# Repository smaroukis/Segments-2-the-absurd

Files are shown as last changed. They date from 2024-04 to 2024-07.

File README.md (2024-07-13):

For now, see <https://maroukis.net/sev-seg> 

> [!CAUTION] You will need to run a `git submodule init && git submodule update` to pull in changes to the TM1637 Seven Segment driver submodule code

## Building 
In the MCU directory i.e. `src/stm32` run `make flash`, see Makefile and VSCode `tasks.json` for details.

## Dependencies
- a forked version of nimaltd/tm1637 as a submodule in src/.../ThirdParty/tm1637 

Update the submodule _within the submodule directory_:
- `git fetch` && `git merge upstream/main`

# Revision History

## 2024-07-13 - Prototype (v-alpha) Hardware Finished
- __note kicad files and production gerbers are not in sync at this point__
- cleaned up git status in preparation for firmware development
- note at this point some edits were made to the kicad files that make it out of sync with the production file from commit #(TODO)
- moved prototype datasheets into a specific folder `.../2024-05-27-v-alpha`

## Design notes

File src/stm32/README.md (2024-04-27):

## Overview

- Build process is via the Makefile using the `arm-none-eabi-gcc` version as installed via the STM32 command line tools 
- Firmware upload & Debuggin is done viaOpenOCD over STLink (transport interface SWD by default?)

Commands:
- Build & Flash at same time via VSCode (`CMD+SHIFT+B`) → Makefile (i.e. `make flash`) → OpenOCD 

## Important files / changes for use

GCC path: is hardcoded and not in system environment variables, but is mainly used in 
- `tasks.json` in the `GCC_PATH` environment variable when we call `make`
- for Intelliense in `c_cpp_properties.json` (for the C/C++ Extension from Microsoft)

Other things to edit
- include paths & define's in the `c_cpp_properties.json`, currently not in use but an example can be found in `c_cpp_properties_old.json` (I think this just affects Intellisense and not compilation)

## Development

(Note currently just using direct commits to `tm1637` `main` branch of submodule)

Due to using submodule (`ThirdParty/tm1637`), development process is as follows
- commit and push and changes for the submodule _before_ commiting changes for the parent
- once submodule changes are pushed, in the project root run `git add ThirdParty/tm1637` (no need for `git fetch`) to add the submodule changes (commit hash should be changed)
- develop, stage, and push changes in the parent project as normal

Tip use
`git submodule status` to see the commit we are pointing to
and compare it to:
```
cd path/to/submodule
git log -1
```

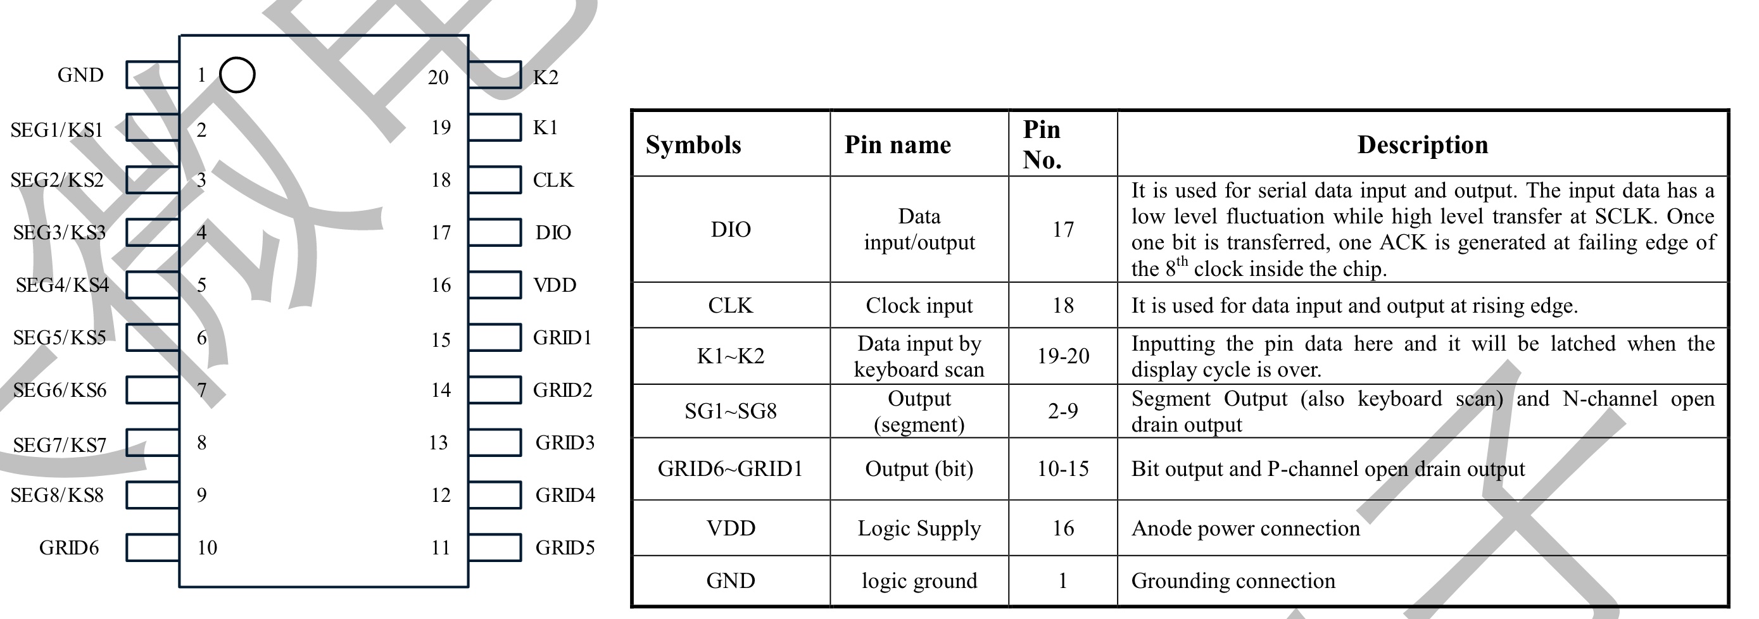
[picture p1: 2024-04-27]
assets/TM1637_pinout-w-description.jpg

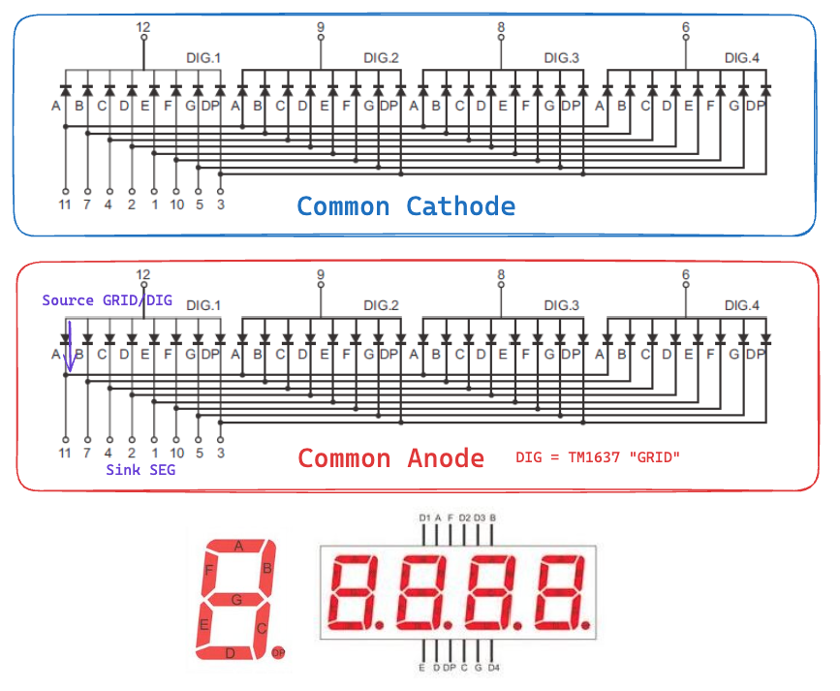
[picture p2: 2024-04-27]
assets/Generic_Seven-Segment_pinout.png

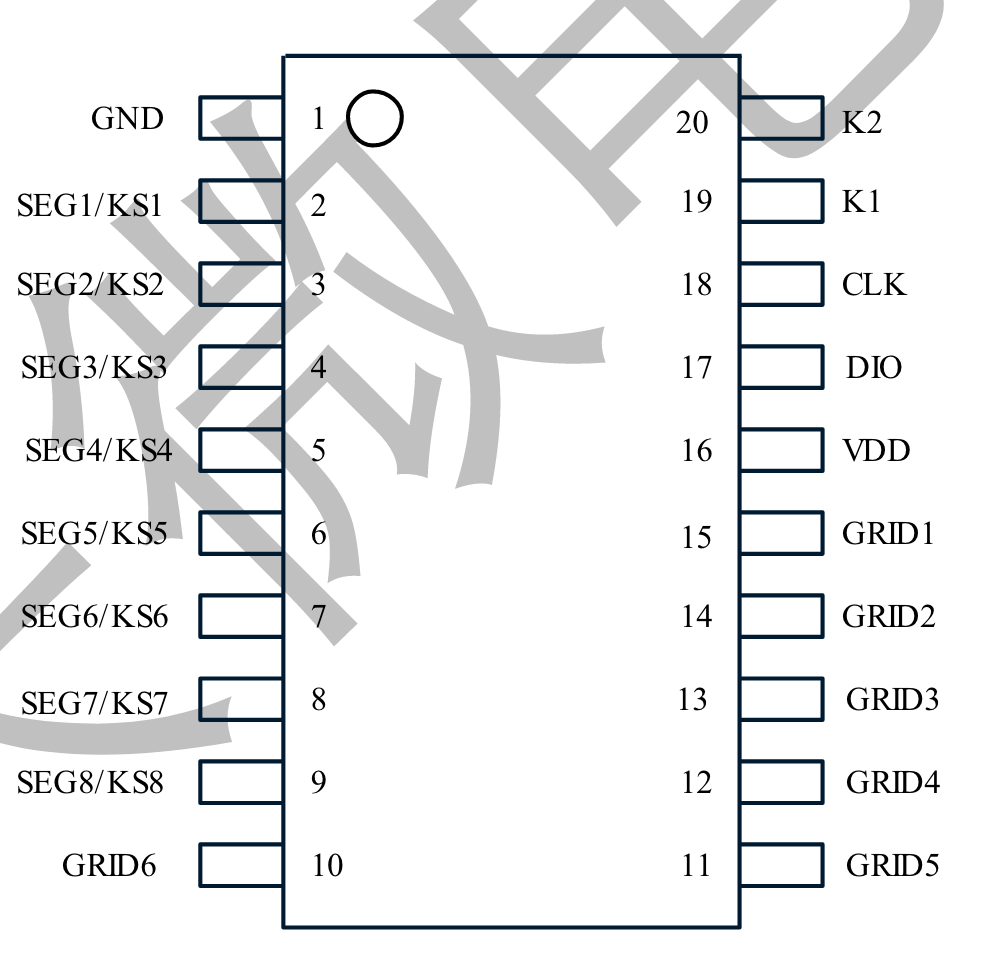
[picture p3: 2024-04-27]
assets/TM1637_pinout.png

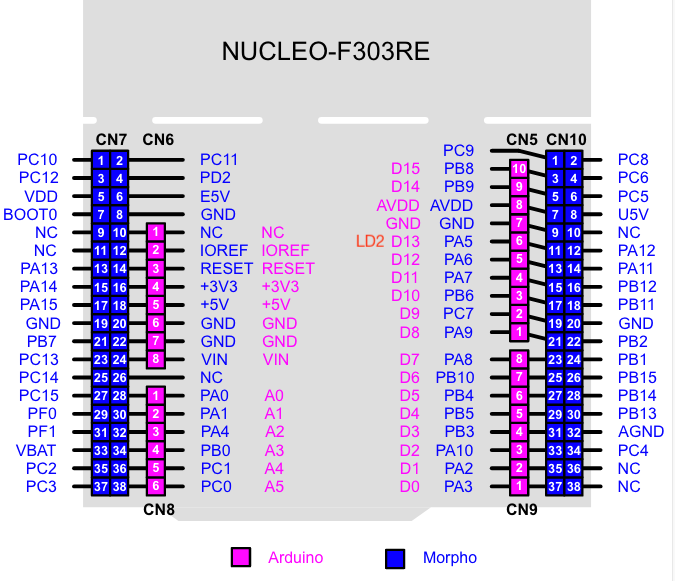
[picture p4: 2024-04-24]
assets/STM-nucleo-f303_pinout.png

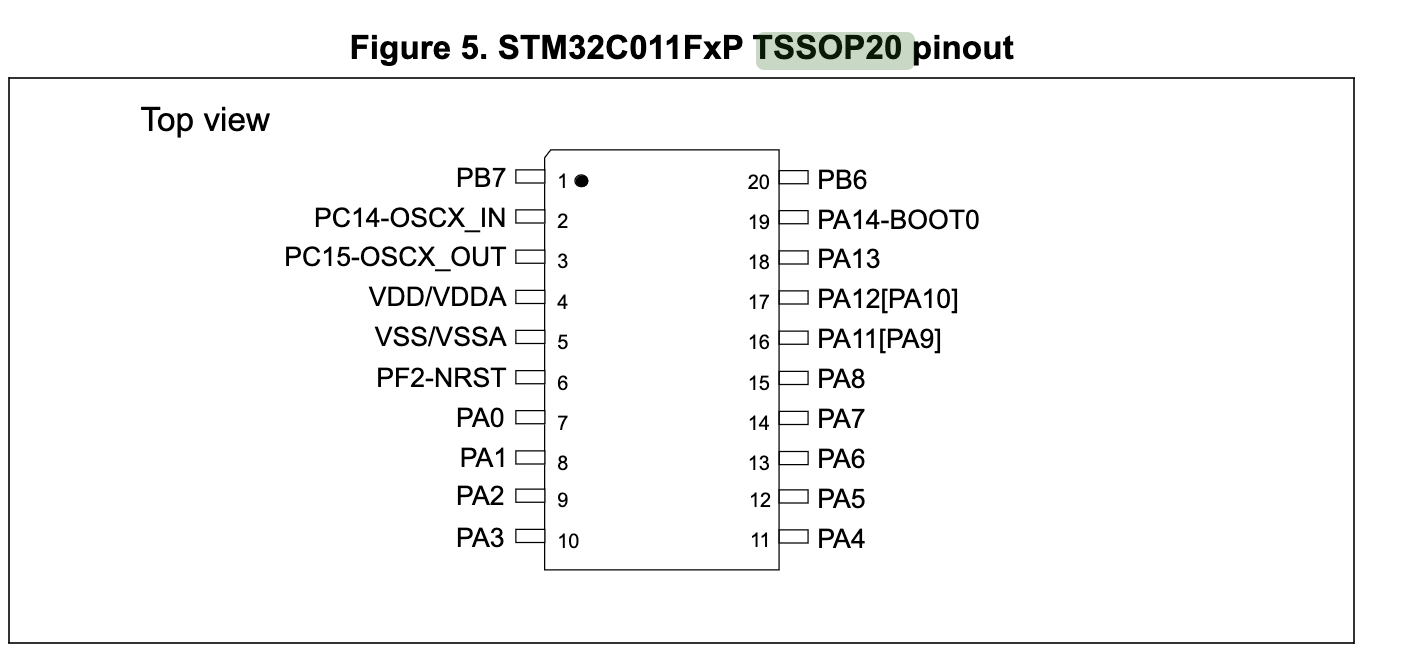
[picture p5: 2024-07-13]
kicad/00-Assets-Datasheets/2024-05-27-v-alpha/mcu-STM32C011F6P6_C5456198_PINOUT.png

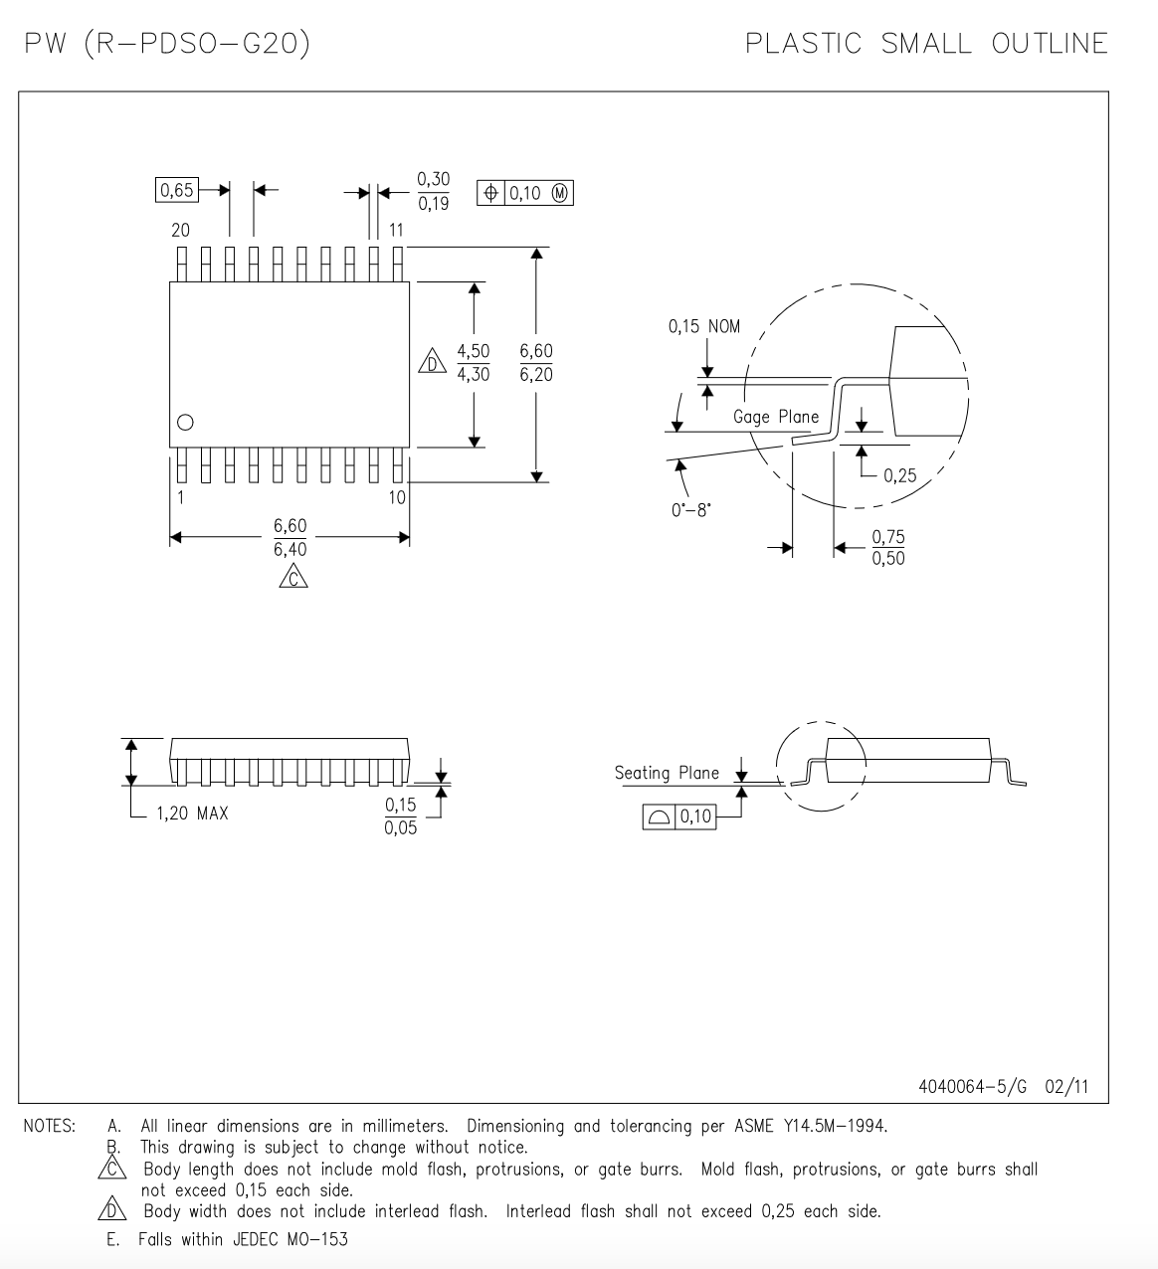
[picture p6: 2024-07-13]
kicad/00-Assets-Datasheets/2024-05-27-v-alpha/level-shifter_Texas-Instruments-TXS0108EPWR_C17206.pdf_PACKAGE.png

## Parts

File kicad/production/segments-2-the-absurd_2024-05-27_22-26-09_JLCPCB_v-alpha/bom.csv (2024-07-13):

Designator | Footprint | Quantity | Comment | LCSC Part #
C1, C13, C17, C21, C24, C26, C27, C28, C29, C31, C32, C33, C35, C39, C43, C5, C9 | 603 | 17 | 100nF | C14663
C10, C11, C14, C15, C18, C19, C22, C23, C36, C37, C40, C41, C44, C45, C6, C7 | 603 | 16 | 100pF | C14858
C12, C16, C20, C34, C38, C4, C42, C8 | 1206 | 8 | 100uF | C15008
C25, C30 | 603 | 2 | 4.7uF | C19666
J10, J11, J12, J13, J14, J15, J16, J17, J20, J9 | PinHeader_1x02_P2.54mm_Vertical | 10 | Conn_01x02_Pin | C492401
J18, J19 | PinHeader_1x03_P1.27mm_Vertical | 2 | Conn_01x03_Pin | DNP
J2 | PinHeader_1x08_P2.54mm_Vertical | 1 | Conn_01x08_Pin | DNP
J4, J6 | PinHeader_1x05_P2.54mm_Vertical | 2 | Conn_01x05_Socket | DNP
J7, J8 | PinHeader_1x02_P1.27mm_Vertical | 2 | Conn_01x02_Pin | DNP
JP1, JP2 | SolderJumper-3_P1.3mm_Bridged12_RoundedPad1.0x1.5mm | 2 | Jumper_3_Bridged12 | DNP
R1, R10, R11, R12, R13, R14, R15, R16, R17, R18, R19, R2, R20, R21, R22, R3, R4, R5, R6, R7, R8, R9 | 603 | 22 | 10K | C25804
U1 | SOP-16_3.9x9.9mm_P1.27mm | 1 | 74HC595 | C5451631
U10, U8 | TSSOP-20_4.4x6.5mm_P0.65mm | 2 | STM32C011F6Px | C5456198
U11, U12, U13, U2, U3, U4, U5, U6 | TM_TM1637(TA2007)_SOC-20_12.6x7.5_P1.27_PD0.44x2 | 8 | TM1637 | C5337160
U7, U9 | TSSOP-20_4.4x6.5mm_P0.65mm | 2 | TXS0108E | C17206

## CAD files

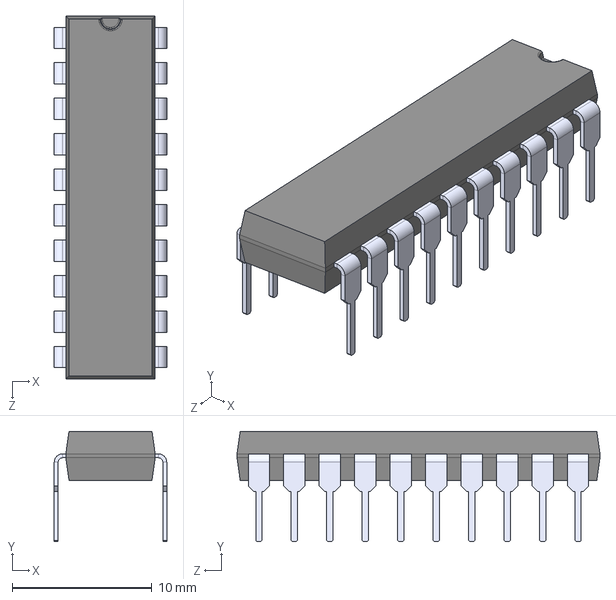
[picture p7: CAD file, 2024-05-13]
kicad/03-3D-Models/TM1637.step
8.06 x 7.91 x 26.0 mm

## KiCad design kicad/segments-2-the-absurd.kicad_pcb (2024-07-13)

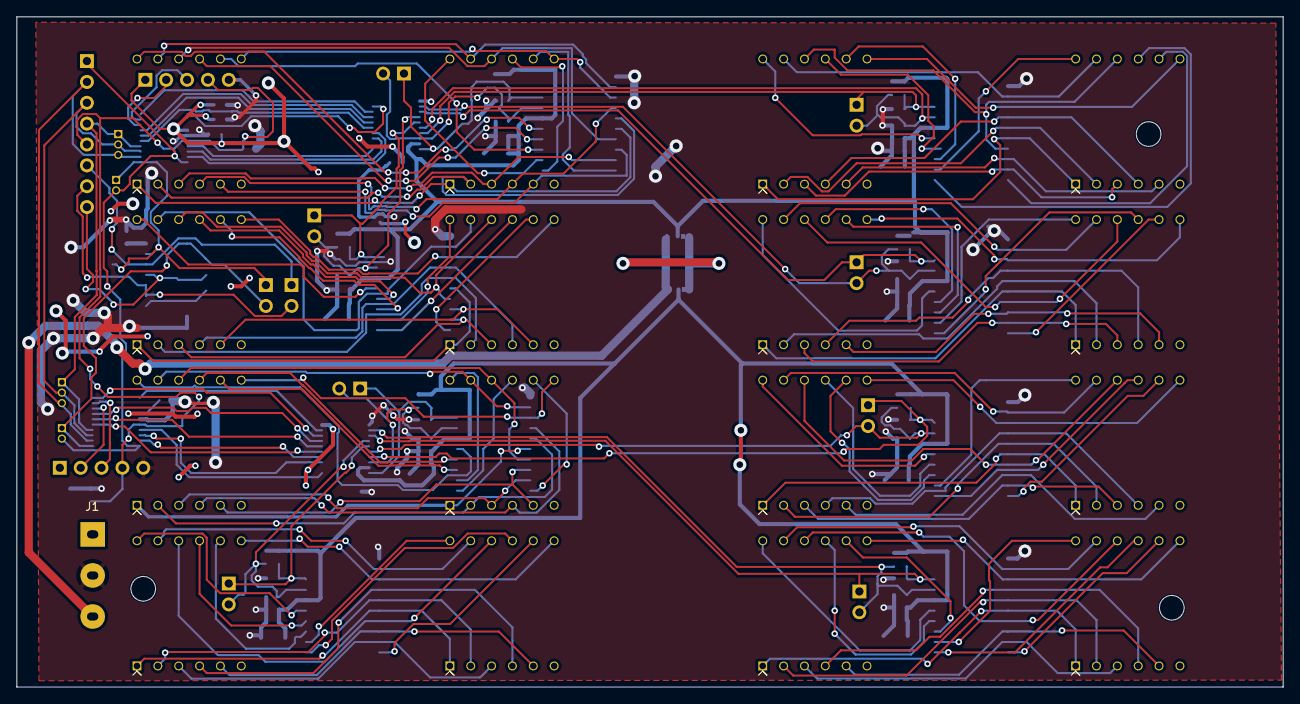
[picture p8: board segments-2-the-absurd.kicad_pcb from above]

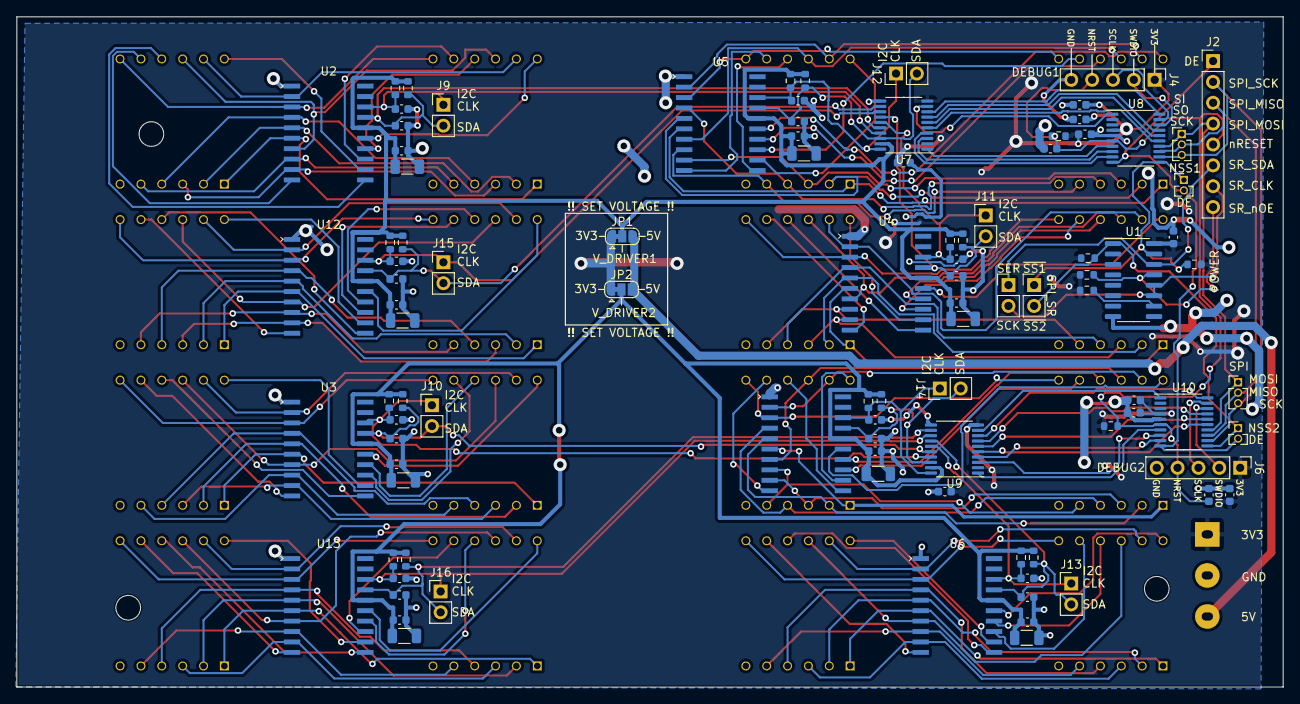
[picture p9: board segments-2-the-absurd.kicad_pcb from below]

Board: 2 copper layers, 154.2 x 81.6 mm, 114 parts (97 on the bottom side), 164 nets.

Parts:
C1, C5, C9, C13, C17, C21, C24, C26, C27, C28, C29, C31, C32, C33, C35, C39, C43: 100nF; C_0603_1608Metric
C4, C8, C12, C16, C20, C34, C38, C42: 100uF; C_1206_3216Metric
C6, C7, C10, C11, C14, C15, C18, C19, C22, C23, C36, C37, C40, C41, C44, C45: 100pF; C_0603_1608Metric
C25, C30: 4.7uF; C_0603_1608Metric
D1, D2, D3, D4, D5, D6, D7, D8, D9, D10, D11, D12, D13, D14, D15, D16: SP410561N; 7-Seg-3D_CA_ARKLED_SP410561N
J1: Conn_01x03_Pin; Power-Conn-3P-D0.65-P5-BD7.8x15
J2: Conn_01x08_Pin; PinHeader_1x08_P2.54mm_Vertical
J4, J6: Conn_01x05_Socket; PinHeader_1x05_P2.54mm_Vertical
J7, J8: Conn_01x02_Pin; PinHeader_1x02_P1.27mm_Vertical
J9, J10, J11, J12, J13, J14, J15, J16, J17, J20: Conn_01x02_Pin; PinHeader_1x02_P2.54mm_Vertical
J18, J19: Conn_01x03_Pin; PinHeader_1x03_P1.27mm_Vertical
JP1, JP2: Jumper_3_Bridged12; SolderJumper-3_P1.3mm_Bridged12_RoundedPad1.0x1.5mm
R1, R2, R3, R4, R5, R6, R7, R8, R9, R10, R11, R12, R13, R14, R15, R16, R17, R18, R19, R20, R21, R22: 10K; R_0603_1608Metric
U1: 74HC595; SOP-16_3.9x9.9mm_P1.27mm
U2, U3, U4, U5, U6, U11, U12, U13: TM1637; TM_TM1637(TA2007)_SOC-20_12.6x7.5_P1.27_PD0.44x2
U7, U9: TXS0108E; TSSOP-20_4.4x6.5mm_P0.65mm
U8, U10: STM32C011F6Px; TSSOP-20_4.4x6.5mm_P0.65mm

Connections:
+3V3: C1.2, C24.1, C25.1, C26.1, C28.2, C29.1, C30.1, C31.1, C33.2, J1.1, J4.1, J6.1, JP1.1 (A), JP2.1 (A), R1.1, R2.1, R3.1, R4.1, R15.1, R16.1, U1.16 (VCC), U7.2 (VCCA), U7.10 (OE), U8.4 (VDD), U9.2 (VCCA), U9.10 (OE), U10.4 (VDD)
+5V: J1.3, JP1.3 (B), JP2.3 (B)
/DISP_EN: J2.1, J7.2, J8.2, U8.10 (PA3), U10.10 (PA3)
/S2A_Serf1/A_CLK: C19.1, J12.1, R12.2, U5.18 (CLK), U7.20 (B1)
/S2A_Serf1/A_CLK': U7.1 (A1), U8.7 (PA0)
/S2A_Serf1/A_DAT: C18.1, J12.2, R11.2, U5.17 (DIO), U7.18 (B2)
/S2A_Serf1/A_DAT': U7.3 (A2), U8.8 (PA1)
/S2A_Serf1/B_CLK: C7.1, J9.1, R6.2, U2.18 (CLK), U7.17 (B3)
/S2A_Serf1/B_CLK': U7.4 (A3), U8.9 (PA2)
/S2A_Serf1/B_DAT: C6.1, J9.2, R5.2, U2.17 (DIO), U7.16 (B4)
/S2A_Serf1/B_DAT': U7.5 (A4), U8.15 (PA8)
/S2A_Serf1/C_CLK: C15.1, J11.1, R10.2, U4.18 (CLK), U7.15 (B5)
/S2A_Serf1/C_CLK': U7.6 (A5), U8.16 (PA9/PA11)
/S2A_Serf1/C_DAT: C14.1, J11.2, R9.2, U4.17 (DIO), U7.14 (B6)
/S2A_Serf1/C_DAT': U7.7 (A6), U8.17 (PA10/PA12)
/S2A_Serf1/D_CLK: C41.1, J15.1, R20.2, U7.13 (B7), U12.18 (CLK)
/S2A_Serf1/D_CLK': U7.8 (A7), U8.20 (PB6)
/S2A_Serf1/D_DAT: C40.1, J15.2, R19.2, U7.12 (B8), U12.17 (DIO)
/S2A_Serf1/D_DAT': U7.9 (A8), U8.1 (PB7)
/S2A_Serf1/SWCLK_BOOT0: J4.3, U8.19 (PA14)
/S2A_Serf1/SWDIO: J4.2, U8.18 (PA13)
/S2A_Serf1/V_DRIVER: C4.1, C5.1, C12.1, C13.1, C16.1, C17.1, C38.1, C39.1, JP1.2 (C), R5.1, R6.1, R9.1, R10.1, R11.1, R12.1, R19.1, R20.1, U2.16 (VDD), U4.16 (VDD), U5.16 (VDD), U7.19 (VCCB), U12.16 (VDD)
/S2A_Serf2/A_CLK: C37.1, J14.1, R18.2, U9.20 (B1), U11.18 (CLK)
/S2A_Serf2/A_CLK': U9.1 (A1), U10.7 (PA0)
/S2A_Serf2/A_DAT: C36.1, J14.2, R17.2, U9.18 (B2), U11.17 (DIO)
/S2A_Serf2/A_DAT': U9.3 (A2), U10.8 (PA1)
/S2A_Serf2/B_CLK: C11.1, J10.1, R8.2, U3.18 (CLK), U9.17 (B3)
/S2A_Serf2/B_CLK': U9.4 (A3), U10.9 (PA2)
/S2A_Serf2/B_DAT: C10.1, J10.2, R7.2, U3.17 (DIO), U9.16 (B4)
/S2A_Serf2/B_DAT': U9.5 (A4), U10.15 (PA8)
/S2A_Serf2/C_CLK: C23.1, J13.1, R14.2, U6.18 (CLK), U9.15 (B5)
/S2A_Serf2/C_CLK': U9.6 (A5), U10.16 (PA9/PA11)
/S2A_Serf2/C_DAT: C22.1, J13.2, R13.2, U6.17 (DIO), U9.14 (B6)
/S2A_Serf2/C_DAT': U9.7 (A6), U10.17 (PA10/PA12)
/S2A_Serf2/D_CLK: C45.1, J16.1, R22.2, U9.13 (B7), U13.18 (CLK)
/S2A_Serf2/D_CLK': U9.8 (A7), U10.20 (PB6)
/S2A_Serf2/D_DAT: C44.1, J16.2, R21.2, U9.12 (B8), U13.17 (DIO)
/S2A_Serf2/D_DAT': U9.9 (A8), U10.1 (PB7)
/S2A_Serf2/SWCLK_BOOT0: J6.3, U10.19 (PA14)
/S2A_Serf2/SWDIO: J6.2, U10.18 (PA13)
/S2A_Serf2/V_DRIVER: C8.1, C9.1, C20.1, C21.1, C34.1, C35.1, C42.1, C43.1, JP2.2 (C), R7.1, R8.1, R13.1, R14.1, R17.1, R18.1, R21.1, R22.1, U3.16 (VDD), U6.16 (VDD), U9.19 (VCCB), U11.16 (VDD), U13.16 (VDD)
/SPI_MISO: J2.3, J18.2, J19.2, U8.13 (PA6), U10.13 (PA6)
/SPI_MOSI: J2.4, J18.1, J19.1, U8.14 (PA7), U10.14 (PA7)
/SPI_NSS1: J7.1, J20.1, R1.2, U1.15 (QA), U8.11 (PA4)
/SPI_NSS2: J8.1, J20.2, R2.2, U1.1 (QB), U10.11 (PA4)
/SPI_SCK: J2.2, J18.3, J19.3, U8.12 (PA5), U10.12 (PA5)
/nRESET_ALL: C27.1, C32.1, J2.5, J4.4, J6.4, R15.2, R16.2, U8.6 (PF2), U10.6 (PF2)
/nSS_CLK: J2.7, J17.2, U1.11 (SRCLK), U1.12 (RCLK)
/nSS_SDA: J2.6, J17.1, U1.14 (SER)
/nSS_nOE: J2.8, R3.2, U1.13 (~OE)
GND: C1.1, C4.2, C5.2, C6.2, C7.2, C8.2, C9.2, C10.2, C11.2, C12.2, C13.2, C14.2, C15.2, C16.2, C17.2, C18.2, C19.2, C20.2, C21.2, C22.2, C23.2, C24.2, C25.2, C26.2, C27.2, C28.1, C29.2, C30.2, C31.2, C32.2, C33.1, C34.2, C35.2, C36.2, C37.2, C38.2, C39.2, C40.2, C41.2, C42.2, C43.2, C44.2, C45.2, J1.2, J4.5, J6.5, U1.8 (GND), U2.1 (GND), U3.1 (GND), U4.1 (GND), U5.1 (GND), U6.1 (GND), U7.11 (GND), U8.5 (VSS), U9.11 (GND), U10.5 (VSS), U11.1 (GND), U12.1 (GND), U13.1 (GND)
unnamed: D1.12 (DIG1), U5.15 (GRID1)
unnamed: D1.9 (DIG2), U5.14 (GRID2)
unnamed: D1.8 (DIG3), U5.13 (GRID3)
unnamed: D1.3 (DPX), D2.3 (DPX), U5.9 (SEG8/KS8)
unnamed: D1.11 (a), D2.11 (a), U5.2 (SEG1/KS1)
unnamed: D1.7 (b), D2.7 (b), U5.3 (SEG2/KS2)
unnamed: D1.4 (c), D2.4 (c), U5.4 (SEG3/KS3)
unnamed: D1.2 (d), D2.2 (d), U5.5 (SEG4/KS4)
unnamed: D1.1 (e), D2.1 (e), U5.6 (SEG5/KS5)
unnamed: D1.10 (f), D2.10 (f), U5.7 (SEG6/KS6)
unnamed: D1.5 (g), D2.5 (g), U5.8 (SEG7/KS7)
unnamed: D2.12 (DIG1), U5.12 (GRID4)
unnamed: D2.9 (DIG2), U5.11 (GRID5)
unnamed: D2.8 (DIG3), U5.10 (GRID6)
unnamed: D3.12 (DIG1), U2.15 (GRID1)
unnamed: D3.9 (DIG2), U2.14 (GRID2)
unnamed: D3.8 (DIG3), U2.13 (GRID3)
unnamed: D3.3 (DPX), D4.3 (DPX), U2.9 (SEG8/KS8)
unnamed: D3.11 (a), D4.11 (a), U2.2 (SEG1/KS1)
unnamed: D3.7 (b), D4.7 (b), U2.3 (SEG2/KS2)
unnamed: D3.4 (c), D4.4 (c), U2.4 (SEG3/KS3)
unnamed: D3.2 (d), D4.2 (d), U2.5 (SEG4/KS4)
unnamed: D3.1 (e), D4.1 (e), U2.6 (SEG5/KS5)
unnamed: D3.10 (f), D4.10 (f), U2.7 (SEG6/KS6)
unnamed: D3.5 (g), D4.5 (g), U2.8 (SEG7/KS7)
unnamed: D4.12 (DIG1), U2.12 (GRID4)
unnamed: D4.9 (DIG2), U2.11 (GRID5)
unnamed: D4.8 (DIG3), U2.10 (GRID6)
unnamed: D5.12 (DIG1), U4.15 (GRID1)
unnamed: D5.9 (DIG2), U4.14 (GRID2)
unnamed: D5.8 (DIG3), U4.13 (GRID3)
unnamed: D5.3 (DPX), D6.3 (DPX), U4.9 (SEG8/KS8)
unnamed: D5.11 (a), D6.11 (a), U4.2 (SEG1/KS1)
unnamed: D5.7 (b), D6.7 (b), U4.3 (SEG2/KS2)
unnamed: D5.4 (c), D6.4 (c), U4.4 (SEG3/KS3)
unnamed: D5.2 (d), D6.2 (d), U4.5 (SEG4/KS4)
unnamed: D5.1 (e), D6.1 (e), U4.6 (SEG5/KS5)
unnamed: D5.10 (f), D6.10 (f), U4.7 (SEG6/KS6)
unnamed: D5.5 (g), D6.5 (g), U4.8 (SEG7/KS7)
unnamed: D6.12 (DIG1), U4.12 (GRID4)
unnamed: D6.9 (DIG2), U4.11 (GRID5)
unnamed: D6.8 (DIG3), U4.10 (GRID6)
unnamed: D7.12 (DIG1), U12.15 (GRID1)
unnamed: D7.9 (DIG2), U12.14 (GRID2)
unnamed: D7.8 (DIG3), U12.13 (GRID3)
unnamed: D7.3 (DPX), D8.3 (DPX), U12.9 (SEG8/KS8)
unnamed: D7.11 (a), D8.11 (a), U12.2 (SEG1/KS1)
unnamed: D7.7 (b), D8.7 (b), U12.3 (SEG2/KS2)
unnamed: D7.4 (c), D8.4 (c), U12.4 (SEG3/KS3)
unnamed: D7.2 (d), D8.2 (d), U12.5 (SEG4/KS4)
unnamed: D7.1 (e), D8.1 (e), U12.6 (SEG5/KS5)
unnamed: D7.10 (f), D8.10 (f), U12.7 (SEG6/KS6)
unnamed: D7.5 (g), D8.5 (g), U12.8 (SEG7/KS7)
unnamed: D8.12 (DIG1), U12.12 (GRID4)
unnamed: D8.9 (DIG2), U12.11 (GRID5)
unnamed: D8.8 (DIG3), U12.10 (GRID6)
unnamed: D9.12 (DIG1), U11.15 (GRID1)
unnamed: D9.9 (DIG2), U11.14 (GRID2)
unnamed: D9.8 (DIG3), U11.13 (GRID3)
unnamed: D10.12 (DIG1), U11.12 (GRID4)
unnamed: D10.9 (DIG2), U11.11 (GRID5)
unnamed: D10.8 (DIG3), U11.10 (GRID6)
unnamed: D9.3 (DPX), D10.3 (DPX), U11.9 (SEG8/KS8)
unnamed: D9.11 (a), D10.11 (a), U11.2 (SEG1/KS1)
unnamed: D9.7 (b), D10.7 (b), U11.3 (SEG2/KS2)
unnamed: D9.4 (c), D10.4 (c), U11.4 (SEG3/KS3)
unnamed: D9.2 (d), D10.2 (d), U11.5 (SEG4/KS4)
unnamed: D9.1 (e), D10.1 (e), U11.6 (SEG5/KS5)
unnamed: D9.10 (f), D10.10 (f), U11.7 (SEG6/KS6)
unnamed: D9.5 (g), D10.5 (g), U11.8 (SEG7/KS7)
unnamed: D11.12 (DIG1), U3.15 (GRID1)
unnamed: D11.9 (DIG2), U3.14 (GRID2)
unnamed: D11.8 (DIG3), U3.13 (GRID3)
unnamed: D11.3 (DPX), D12.3 (DPX), U3.9 (SEG8/KS8)
unnamed: D11.11 (a), D12.11 (a), U3.2 (SEG1/KS1)
unnamed: D11.7 (b), D12.7 (b), U3.3 (SEG2/KS2)
unnamed: D11.4 (c), D12.4 (c), U3.4 (SEG3/KS3)
unnamed: D11.2 (d), D12.2 (d), U3.5 (SEG4/KS4)
unnamed: D11.1 (e), D12.1 (e), U3.6 (SEG5/KS5)
unnamed: D11.10 (f), D12.10 (f), U3.7 (SEG6/KS6)
unnamed: D11.5 (g), D12.5 (g), U3.8 (SEG7/KS7)
unnamed: D12.12 (DIG1), U3.12 (GRID4)
unnamed: D12.9 (DIG2), U3.11 (GRID5)
unnamed: D12.8 (DIG3), U3.10 (GRID6)
unnamed: D13.12 (DIG1), U6.15 (GRID1)
unnamed: D13.9 (DIG2), U6.14 (GRID2)
unnamed: D13.8 (DIG3), U6.13 (GRID3)
unnamed: D13.3 (DPX), D14.3 (DPX), U6.9 (SEG8/KS8)
unnamed: D13.11 (a), D14.11 (a), U6.2 (SEG1/KS1)
unnamed: D13.7 (b), D14.7 (b), U6.3 (SEG2/KS2)
unnamed: D13.4 (c), D14.4 (c), U6.4 (SEG3/KS3)
unnamed: D13.2 (d), D14.2 (d), U6.5 (SEG4/KS4)
unnamed: D13.1 (e), D14.1 (e), U6.6 (SEG5/KS5)
unnamed: D13.10 (f), D14.10 (f), U6.7 (SEG6/KS6)
unnamed: D13.5 (g), D14.5 (g), U6.8 (SEG7/KS7)
unnamed: D14.12 (DIG1), U6.12 (GRID4)
unnamed: D14.9 (DIG2), U6.11 (GRID5)
unnamed: D14.8 (DIG3), U6.10 (GRID6)
unnamed: D15.12 (DIG1), U13.15 (GRID1)
unnamed: D15.9 (DIG2), U13.14 (GRID2)
unnamed: D15.8 (DIG3), U13.13 (GRID3)
unnamed: D15.3 (DPX), D16.3 (DPX), U13.9 (SEG8/KS8)
unnamed: D15.11 (a), D16.11 (a), U13.2 (SEG1/KS1)
unnamed: D15.7 (b), D16.7 (b), U13.3 (SEG2/KS2)
unnamed: D15.4 (c), D16.4 (c), U13.4 (SEG3/KS3)
unnamed: D15.2 (d), D16.2 (d), U13.5 (SEG4/KS4)
unnamed: D15.1 (e), D16.1 (e), U13.6 (SEG5/KS5)
unnamed: D15.10 (f), D16.10 (f), U13.7 (SEG6/KS6)
unnamed: D15.5 (g), D16.5 (g), U13.8 (SEG7/KS7)
unnamed: D16.12 (DIG1), U13.12 (GRID4)
unnamed: D16.9 (DIG2), U13.11 (GRID5)
unnamed: D16.8 (DIG3), U13.10 (GRID6)
unnamed: R4.2, U1.10 (~SRCLR)

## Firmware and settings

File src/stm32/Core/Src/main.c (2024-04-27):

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
/* Includes ------------------------------------------------------------------*/
#include "main.h"
#include "usart.h"
#include "gpio.h"
#include "tm1637.h"
#include "tm1637_helpers.c"

/* USER CODE BEGIN PD */
// TODO check pins
#define TM1637_CLK_PORT GPIOB
#define TM1637_CLK_PIN GPIO_PIN_8
#define TM1637_DIO_PORT GPIOB
#define TM1637_DIO_PIN GPIO_PIN_9

#define SET_SEGMENTS 1
#define RESET_SEGMENTS 0

/* USER CODE END PD */

tm1637_t tm1637;

void SystemClock_Config(void);
/**
  * @brief  The application entry point.
  * @retval int
  */
int main(void)
{

  /* MCU Configuration--------------------------------------------------------*/

  /* Reset of all peripherals, Initializes the Flash interface and the Systick. */
  HAL_Init();

  /* Configure the system clock */
  SystemClock_Config();

  /* Initialize all configured peripherals */
  MX_GPIO_Init();
  MX_USART2_UART_Init();
  /* USER CODE BEGIN 2 */
  tm1637_init(&tm1637, TM1637_CLK_PORT, TM1637_CLK_PIN, TM1637_DIO_PORT, TM1637_DIO_PIN);

  /* USER CODE END 2 */

  /* Infinite loop */
  /* USER CODE BEGIN WHILE */
  bool toggleEnableDisable;
  int pos = 0;
  int dir = 1;
  while (1)
  {
    HAL_GPIO_TogglePin(LD2_GPIO_Port, LD2_Pin);

    // TM1637 Code
    // tm1637_fill(&tm1637, toggleEnableDisable = !toggleEnableDisable);
    // display_ex3(&tm1637); 
    display_fade(&tm1637);

    /* USER CODE END WHILE */

    /* USER CODE BEGIN 3 */
  }
  /* USER CODE END 3 */
}

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


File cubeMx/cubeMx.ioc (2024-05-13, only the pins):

Mcu.UserName=STM32C011F4Px
PA0.GPIO_Label=GPIO_A_CLK
PA0.Signal=GPIO_Output
PA1.GPIO_Label=GPIO_A_DAT
PA1.Signal=GPIO_Output
PA13.Signal=DEBUG_SWDIO
PA14-BOOT0.Signal=DEBUG_SWCLK
PA2.GPIO_Label=GPIO_B_CLK
PA2.Signal=GPIO_Output
PA3.Signal=GPIO_Output
PA4.Signal=SPI1_NSS
PA5.Signal=SPI1_SCK
PA6.Signal=SPI1_MISO
PA7.Signal=SPI1_MOSI
PA8.GPIO_Label=GPIO_B_DAT
PA8.Signal=GPIO_Output

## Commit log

2024-05-13 commit 1
    [S2A_Serf_STM32C0.kicad_sch, TM1637.step, segments-2-the-absurd.kicad_pcb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]
2024-07-13 adding v-alpha prototype gerbers (note out of sync with kicad files)
    [S2A_Serf_STM32C0.kicad_sch, bom.csv, bom_no_dnp.csv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]
2024-07-13 added prototype datasheets

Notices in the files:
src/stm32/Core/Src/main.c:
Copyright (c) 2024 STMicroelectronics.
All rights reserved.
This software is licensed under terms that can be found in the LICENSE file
